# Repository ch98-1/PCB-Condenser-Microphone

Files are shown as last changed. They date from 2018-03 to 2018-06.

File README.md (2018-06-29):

# PCB-Condenser-Microphone
Basic Condenser microphone kit that uses the PCB as a backplate. It is highly recommended to get the pcb manifactured with ENIG finish for flatness and corrosion resistance. For standalone use, it is recommended to go with the shielded design. For the opamp, any 8SOICopamp with the same pinout as LM358 should be able to replace the one on the board, and lower noise opamp such as OPA1678 is recommended for less static.
For more information, visit corwinh.com/pcm or read the assembly instructions in the PCB-Condenser-Microphone.pdf file in the instruction-manual directory.

**License**

All files are licensed under [zlib license](https://opensource.org/licenses/Zlib) unless noted otherwise.
Some KiCad Library Files (PCB-Condenser-Microphone/PCB-Condenser-Microphone-cache.lib PCB-Condenser-Microphone-Backplate/PCB-Condenser-Microphone-Backplate-cache.lib and PCB-Condenser-Microphone-Clamp/PCB-Condenser-Microphone-Clamp-cache.lib) are licensed under [KiCad Libraries License] (http://kicad-pcb.org/libraries/license/)

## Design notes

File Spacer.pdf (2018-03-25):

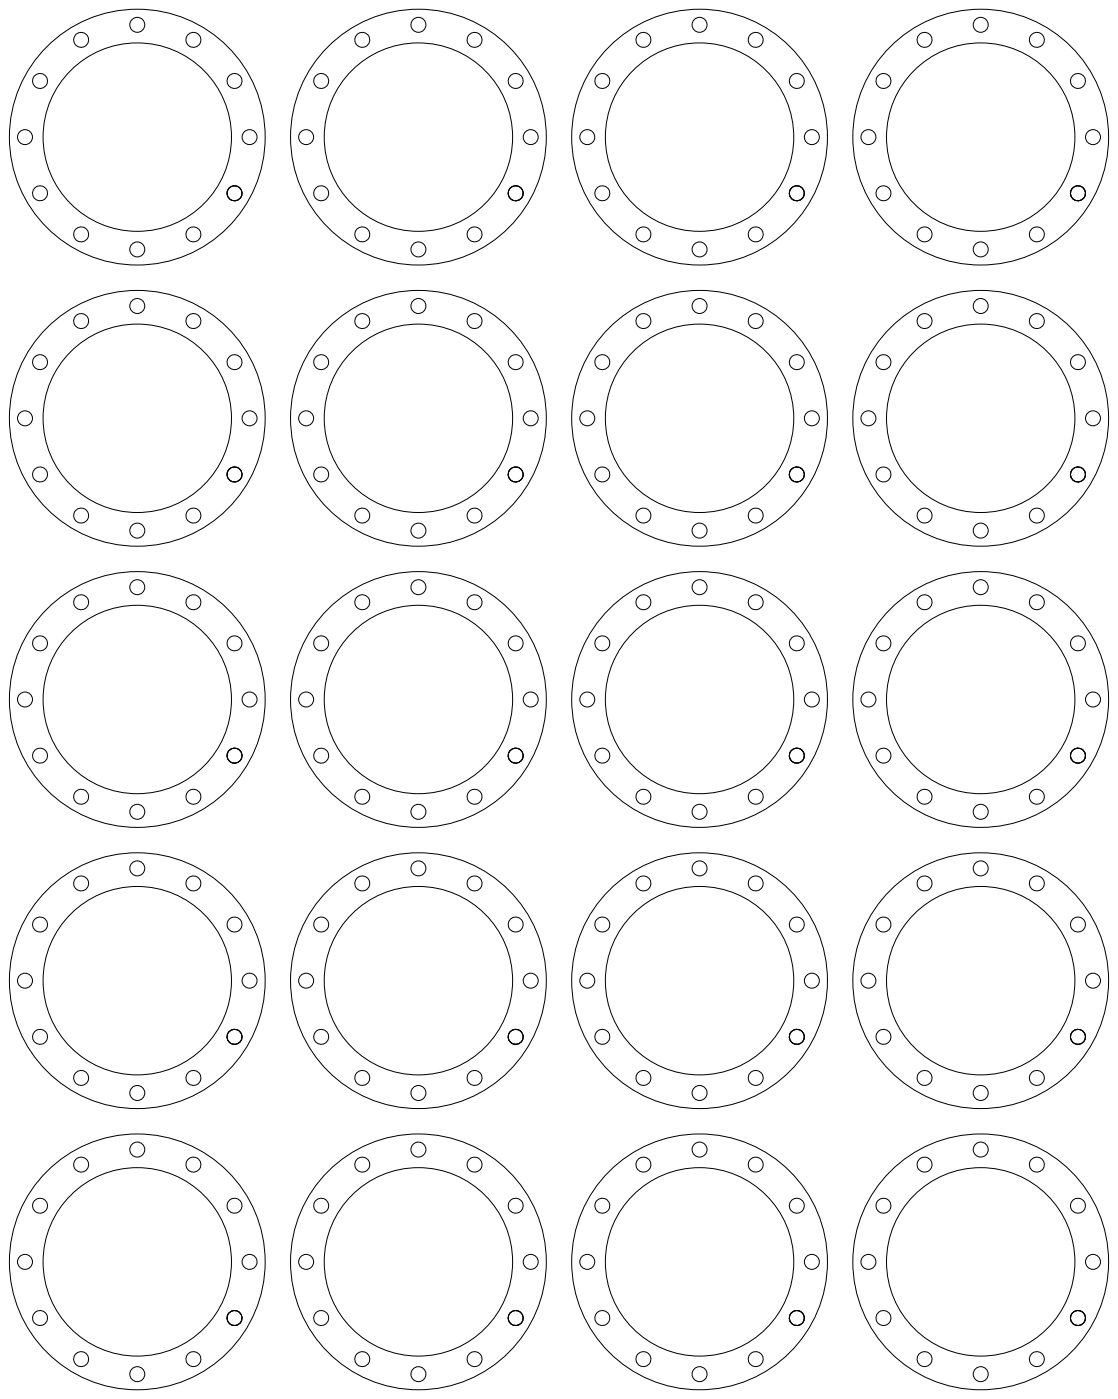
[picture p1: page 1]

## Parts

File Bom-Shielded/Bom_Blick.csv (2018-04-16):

Black item number | Product Link | Quantity | Description
33408-8220 | https://www.dickblick.com/items/33408-8220/ | 3 squre inches (1.75in x 1.75in square) | woven 80 mesh brass Amaco Wireform Mesh 16in × 20in
63201-1036 | https://www.dickblick.com/items/63201-1036/ | 1.6 squre inches (1.25in x 1.25in square) | Polyester Felt per yard White 36in wide

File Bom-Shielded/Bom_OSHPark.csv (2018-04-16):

OSH Park Project Link | Quantity | Description
https://oshpark.com/shared_projects/7XHldnvE | 1 | Preamp board for pcb condenser microphone
https://oshpark.com/shared_projects/KuCUYLwc | 1 | Backplate for pcb condenser microphone capsule
https://oshpark.com/shared_projects/s9UbMv0x | 1 | Clamp for pcb condenser microphone capsule

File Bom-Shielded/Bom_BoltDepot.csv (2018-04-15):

Bolt Depot Product Number | Product Link | Quantity | Description
22990 | https://www.boltdepot.com/Product-Details.aspx?product=22990 | 24 | Metric hex nuts, Stainless steel 316 (A-4), 2mm x 0.4mm
22188 | https://www.boltdepot.com/Product-Details.aspx?product=22188 | 12 | Metric machine screws, Phillips pan head, Stainless steel 316 (A-4), 2mm x 0.4mm x 8mm

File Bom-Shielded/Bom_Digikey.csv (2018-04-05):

Manufacturer Part Number | Manufacturer | Digi-Key Part Number | Customer Reference | Quantity | Description
BS6I | MPD (Memory Protection Devices) | BS6I-ND | J1 | 1 | SNAPS 9V 6" LEADS I-STYLE
SJ-3523-SMT-TR | CUI Inc. | CP-3523SJCT-ND | J2 | 1 | CONN JACK STEREO 3.5MM SMD R/A
6LF22XWA/B | Panasonic - BSG | P687-ND |  | 1 | BATTERY ALKALINE 9V
GRM21BR61E106KA73L | Murata Electronics North America | 490-5523-1-ND | C2-C4 | 3 | CAP CER 10UF 25V X5R 0805
ERJ-2RKF1002X | Panasonic Electronic Components | P10.0KLCT-ND | R3-R7 | 5 | RES SMD 10K OHM 1% 1/10W 0402
150060RS75000 | Wurth Electronics Inc. | 732-4978-1-ND | D1 | 1 | LED RED CLEAR 0603 SMD
ERJ-2RKF1001X | Panasonic Electronic Components | P1.00KLCT-ND | R1, R2 | 3 | RES SMD 1K OHM 1% 1/10W 0402
LM358ADR | Texas Instruments | 296-14601-1-ND | U1 | 1 | IC OPAMP GP 700KHZ 8SOIC
TC33X-2-104E | Bourns Inc. | TC33X-104ECT-ND | RV1 | 1 | TRIMMER 100K OHM 0.1W SMD
GRM188R71C474KA88D | Murata Electronics North America | 490-3295-1-ND | C1 | 1 | CAP CER 0.47UF 16V X7R 0603
ERJ-2RKF1003X | Panasonic Electronic Components | P100KLCT-ND | R8 | 1 | RES SMD 100K OHM 1% 1/10W 0402
JS102011SAQN | C&K | 401-1999-1-ND | SW1 | 1 | SWITCH SLIDE SPDT 300MA 6V
GCM1885C1H681JA16D | Murata Electronics North America | 490-4966-1-ND | C5 | 1 | CAP CER 680PF 50V C0G/NP0 0603
HMC0402JT100M | Stackpole Electronics Inc. | HMC0402JT100MCT-ND | R9, R10 | 2 | RES 100M OHM 5% 1/16W 0402
MMBF4117 | ON Semiconductor | MMBF4117CT-ND | Q1 | 1 | JFET N-CH 40V 0.225W SOT23

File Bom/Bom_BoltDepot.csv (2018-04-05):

Bolt Depot Product Number | Product Link | Quantity | Description
22990 | https://www.boltdepot.com/Product-Details.aspx?product=22990 | 14 | Metric hex nuts, Stainless steel 316 (A-4), 2mm x 0.4mm
22186 | https://www.boltdepot.com/Product-Details.aspx?product=22186 | 10 | Metric machine screws, Phillips pan head, Stainless steel 316 (A-4), 2mm x 0.4mm x 5mm
22188 | https://www.boltdepot.com/Product-Details.aspx?product=22188 | 2 | Metric machine screws, Phillips pan head, Stainless steel 316 (A-4), 2mm x 0.4mm x 8mm

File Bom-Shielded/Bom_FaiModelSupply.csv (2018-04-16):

Fai Model Supply SKU | Product Link | Quantity | Description
MM050S | https://www.faimodelsupply.com/product/12-mil-metalized-mylar-approx-10-x-6/ | 9 squre inches (3in x 3in square) | 1/2 mil Metalized Mylar approx 10″ X 6′
Or
MM025S | https://www.faimodelsupply.com/product/14-mil-metalized-mylar-approx-12-x-6/ | 9 squre inches (3in x 3in square) | 1/4 mil Metalized Mylar approx 12″ X 6′

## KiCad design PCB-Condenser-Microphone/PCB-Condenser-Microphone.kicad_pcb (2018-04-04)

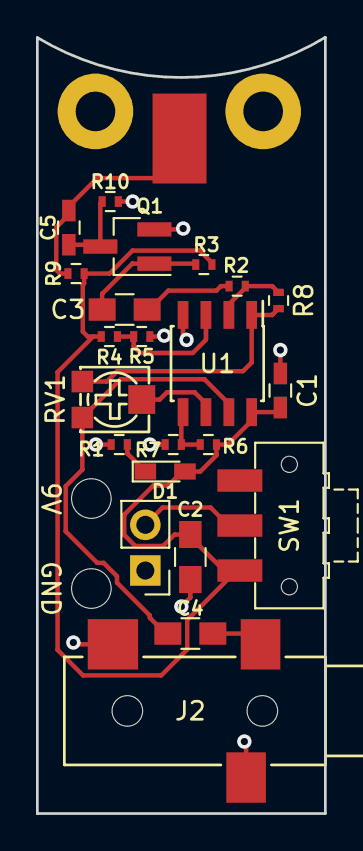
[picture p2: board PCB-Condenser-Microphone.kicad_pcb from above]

Board: 2 copper layers, 16.0 x 43.1 mm, 25 parts (0 on the bottom side), 15 nets.

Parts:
C1: 0.47uF; C_0603_HandSoldering
C2, C3, C4: 10uF; C_0805_HandSoldering
C5: 680pF; C_0603_HandSoldering
D1: LED; LED_0603_HandSoldering
J1: Conn_01x02; Pin_Header_Straight_1x02_Pitch2.54mm
J2: SJ-3523-SMT; SJ-3523-SMT-TR
MK1: Microphone_Condenser; Condenser-Microphone-Backplate-30mm-Single-mount
MT1, MT2: Strain Relief; MountingHole_2.2mm_M2
Q1: Q_NJFET_DSG; SOT-23_Handsoldering
R1, R2: 1k; R_0402
R3: 10K; R_0402
R4, R5, R6, R7: 10k; R_0402
R8: 100k; R_0402
R9, R10: 100M; R_0402
RV1: 100k; TC33X
SW1: SW_SPDT; SW_SPDT_CK-JS102011SAQN
U1: LM358; SOIC-8_3.9x4.9mm_Pitch1.27mm

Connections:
+9V: C1.2, C2.2, D1.2, R3.1, R4.1, R6.1, R9.1, SW1.1, U1.8
GND: C1.1, C2.1, J1.1, J2.1, J2.3, MK1.1, Q1.2, R1.2, R5.2, R7.2, R10.2, U1.4
unnamed: C3.1, R2.2
unnamed: C3.2, Q1.1, R3.2
unnamed: C4.1, J2.2
unnamed: C4.2, RV1.3, U1.7
unnamed: C5.1, Q1.3, R10.1
unnamed: C5.2, MK1.2, R9.2
unnamed: D1.1, R1.1
unnamed: J1.2, SW1.2
unnamed: R2.1, R8.2, U1.2
unnamed: R4.2, R5.1, U1.3
unnamed: R6.2, R7.1, U1.5
unnamed: R8.1, RV1.1, U1.1
unnamed: RV1.2, U1.6

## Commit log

2018-03-10 Created project file
    [PCB-Condenser-Microphone.kicad_pcb, PCB-Condenser-Microphone.sch]
2018-03-11 Created backplate and clamp
    [PCB-Condenser-Microphone-Backplate-B.Cu.gbr, PCB-Condenser-Microphone-Backplate-B.Mask.gbr, PCB-Condenser-Microphone-Backplate-B.Paste.gbr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]
2018-03-13 Created schimatic and added digikey BOM
    [Bom_Digikey.csv, PCB-Condenser-Microphone.sch]
2018-03-13 Added Titles
    [Bom_Digikey.csv, PCB-Condenser-Microphone-Backplate.kicad_pcb, PCB-Condenser-Microphone-Backplate.sch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]
2018-03-13 Layd out pcb and added OSHW logo
    [PCB-Condenser-Microphone.kicad_pcb, PCB-Condenser-Microphone.sch]
2018-03-13 Routed PCB
    [PCB-Condenser-Microphone.kicad_pcb]
2018-03-13 Generated Gerber
    [PCB-Condenser-Microphone-B.Cu.gbr, PCB-Condenser-Microphone-B.Mask.gbr, PCB-Condenser-Microphone-B.Paste.gbr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]
2018-03-14 Fixed an unconnected trace
    [PCB-Condenser-Microphone-B.Cu.gbr, PCB-Condenser-Microphone-B.Mask.gbr, PCB-Condenser-Microphone-B.Paste.gbr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]
2018-03-14 Fixed pcb outline and regenerated gerber
    [PCB-Condenser-Microphone-B.Cu.gbr, PCB-Condenser-Microphone-B.Mask.gbr, PCB-Condenser-Microphone-B.Paste.gbr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]
2018-03-14 Removed silkscreen from clamp
    [PCB-Condenser-Microphone-Clamp-B.Cu.gbr, PCB-Condenser-Microphone-Clamp-B.Mask.gbr, PCB-Condenser-Microphone-Clamp-B.Paste.gbr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]
2018-03-25 Added spacer for printout
2018-03-26 Updated mic backplate to be double sided
    [PCB-Condenser-Microphone-Backplate-B.Cu.gbr, PCB-Condenser-Microphone-Backplate-B.Mask.gbr, PCB-Condenser-Microphone-Backplate-B.Paste.gbr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]
2018-03-26 Updated schimatic to have fet preamp
    [Bom_Digikey.csv, PCB-Condenser-Microphone.sch]
2018-03-26 Updated circuit to match the jfet
    [Bom_Digikey.csv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]
2018-03-26 Uodated JFET
    [Bom_Digikey.csv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]
2018-03-27 Added back OSHW logo to preamp
    [PCB-Condenser-Microphone-B.Cu.gbr, PCB-Condenser-Microphone-B.Mask.gbr, PCB-Condenser-Microphone-B.Paste.gbr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]
2018-03-27 Added recomendation to manifacture the pcb with ENIG finish
2018-03-29 Updated files for new library
    [PCB-Condenser-Microphone-B.Cu.gbr, PCB-Condenser-Microphone-B.Mask.gbr, PCB-Condenser-Microphone-B.Paste.gbr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]
2018-04-04 Switched ground and bias on microphone preamp
    [PCB-Condenser-Microphone-B.Cu.gbr, PCB-Condenser-Microphone-B.Mask.gbr, PCB-Condenser-Microphone-B.Paste.gbr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]
2018-04-04 Added BOM for shielded mic assembly
    [Bom_Digikey_Shielded.csv]
2018-04-04 Updated design to use same bolt for shielded version
    [Bom_Digikey_Shielded.csv]
2018-04-05 Added seperate BOM for fasteners
    [Bom_BoltDepot.csv, Bom_Digikey.csv, Bom_Digikey_Shielded.csv]
2018-04-15 Chenged components after prototyping
    [Bom_BoltDepot.csv]
2018-04-16 Added bom for all other components
    [Bom_Blick.csv, Bom_FaiModelSupply.csv, Bom_OSHPark.csv]

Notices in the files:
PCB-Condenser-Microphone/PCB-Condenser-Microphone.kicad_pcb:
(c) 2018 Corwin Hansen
